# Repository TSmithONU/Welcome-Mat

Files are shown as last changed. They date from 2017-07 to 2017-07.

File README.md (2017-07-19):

# Welcome-Mat
Board files and software for WOSU Welcome Mat

The WOSU Welcome Mat consists of 7 lamps with WOSU logos. The goal of this project was to rebuild and update the previous hardware. To do this, used a Teensy 3.2, VS1053 breakout from Adafruit, and a LiDar sensor.
The LiDar sensor is calibrated to set threshold. When that threshold is crossed, it triggers playback of an audio file. The program contains a command set for use on the serial port. This allows the user to run diagnostic commands.
These include recalibration, scanning the SD card, taking a LiDar reading, and more. This repository contains the custom PCB files, as well as the teensy software.

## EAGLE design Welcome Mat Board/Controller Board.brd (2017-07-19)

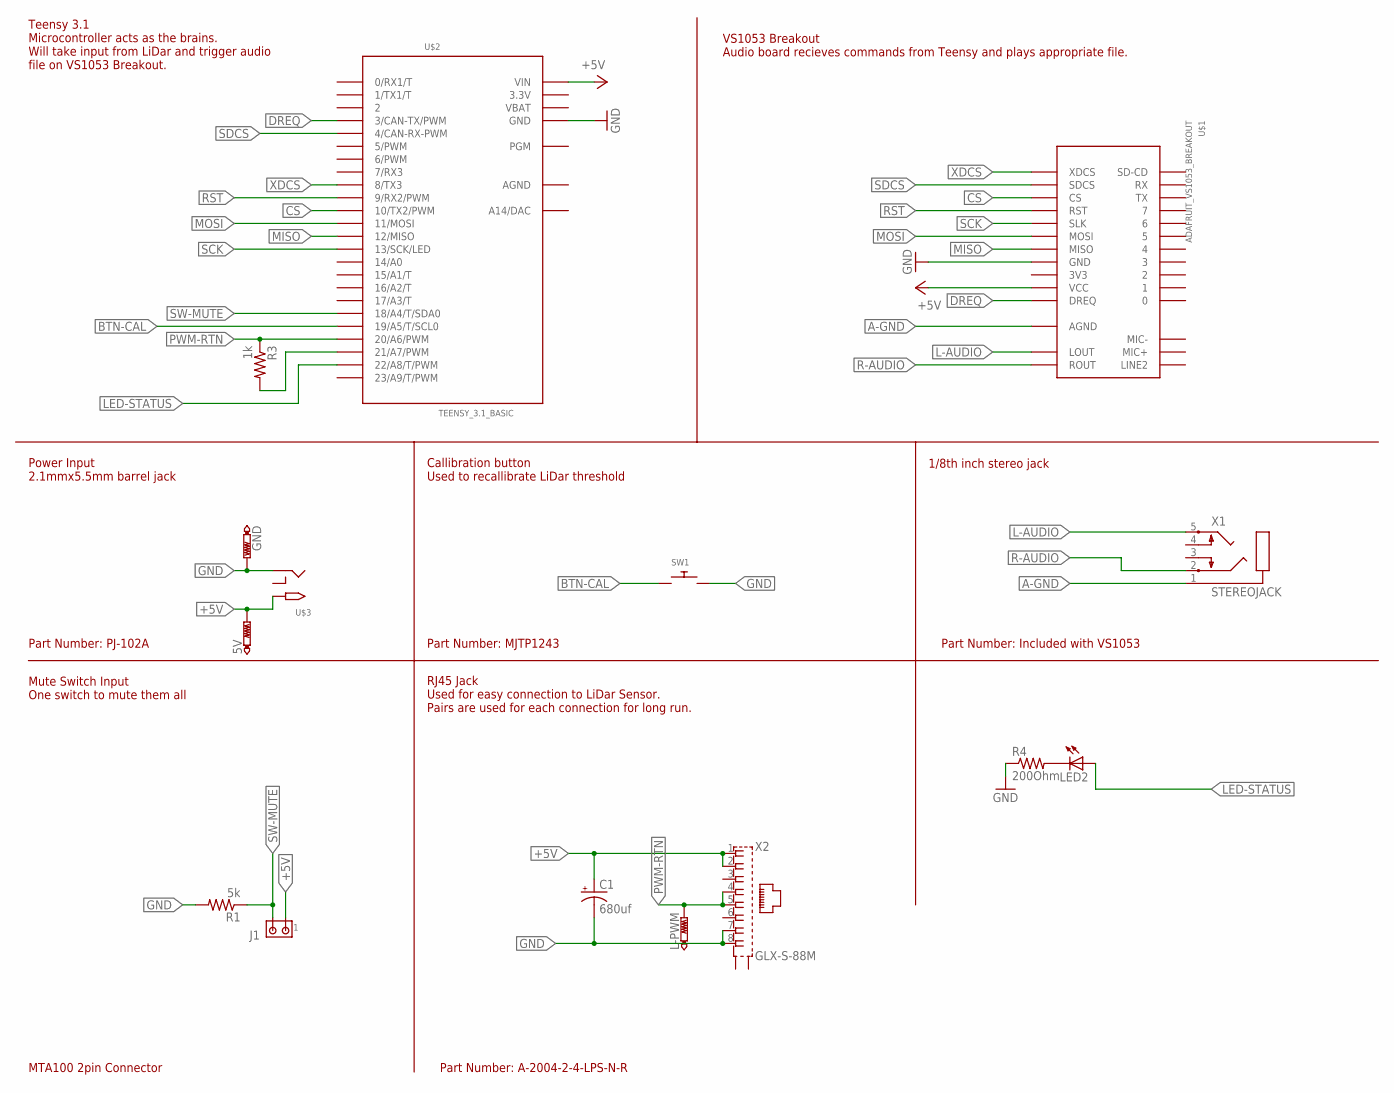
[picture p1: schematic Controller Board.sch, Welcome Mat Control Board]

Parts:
5V: PTR1PAD1-13; P1-13
C1: 680uf; E5-10,5
GND: PTR1PAD1-13; P1-13
J1: MTA02-100; 10X02MTA
L-PWM: PTR1PAD1-13; P1-13
LED2: LED3MM
R1: 5k; 0204/7
R3: 1k; 0204/5
R4: 200Ohm; 0204/7
SW1: SWITCH_PUSHBUTTONEVQ-PE; TACT_PANA-EVQ
U$1: ADAFRUIT_VS1053_BREAKOUT
U$2: TEENSY_3.1_BASIC
U$3: 2.1MMJACKTHM; PJ-102A
X1: STEREOJACK; STX3100
X2: GLX-S-88M

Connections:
3.3V: U$2.3.3V, U$2.3.3V1 (3.3V)
+5V: 5V.TP, C1.+, J1.1, U$1.P$10 (VCC), U$2.VIN, U$3.TIP, X2.1, X2.2
A-GND: U$1.P$13 (AGND), U$1.P$14 (AGND), U$1.P$20 (AGND), X1.1
AGND: U$2.AGND
BTN-CAL: SW1.P$1, U$2.19/A5 (19/A5/T/SCL0)
CS: U$1.P$3 (CS), U$2.10 (10/TX2/PWM)
DREQ: U$1.P$11 (DREQ), U$2.3 (3/CAN-TX/PWM)
GND: C1.-, GND.TP, R1.2, R4.1, SW1.P$2, U$1.P$8 (GND), U$1.P$12 (GND), U$2.GND, U$2.GND1 (GND), U$3.RING, X2.7, X2.8
L-AUDIO: U$1.P$15 (LOUT), X1.5
LED-STATUS: LED2.A, U$2.22/A8 (22/A8/T/PWM)
MISO: U$1.P$7 (MISO), U$2.12 (12/MISO)
MOSI: U$1.P$6 (MOSI), U$2.11 (11/MOSI)
unnamed: R3.2, U$2.21/A7 (21/A7/PWM)
unnamed: LED2.K (C), R4.2
PWM-RTN: L-PWM.TP, R3.1, U$2.20/A6 (20/A6/PWM), X2.4, X2.5
R-AUDIO: U$1.P$16 (ROUT), X1.2
RST: U$1.P$4 (RST), U$2.9 (9/RX2/PWM)
SCK: U$1.P$5 (SLK), U$2.13 (13/SCK/LED)
SDCS: U$1.P$2 (SDCS), U$2.4 (4/CAN-RX-PWM)
SW-MUTE: J1.2, R1.1, U$2.18/A4 (18/A4/T/SDA0)
VBAT: U$2.VBAT
XDCS: U$1.P$1 (XDCS), U$2.8 (8/TX3)

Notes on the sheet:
Teensy 3.1 Microcontroller acts as the brains. Will take input from LiDar and trigger audio file on VS1053 Breakout.
VS1053 Breakout Audio board recieves commands from Teensy and plays appropriate file.
Power Input 2.1mmx5.5mm barrel jack
Callibration button Used to recallibrate LiDar threshold
1/8th inch stereo jack
Mute Switch Input One switch to mute them all
RJ45 Jack Used for easy connection to LiDar Sensor. Pairs are used for each connection for long run.
Part Number: PJ-102A
Part Number: MJTP1243
Part Number: Included with VS1053
MTA100 2pin Connector
Part Number: A-2004-2-4-LPS-N-R

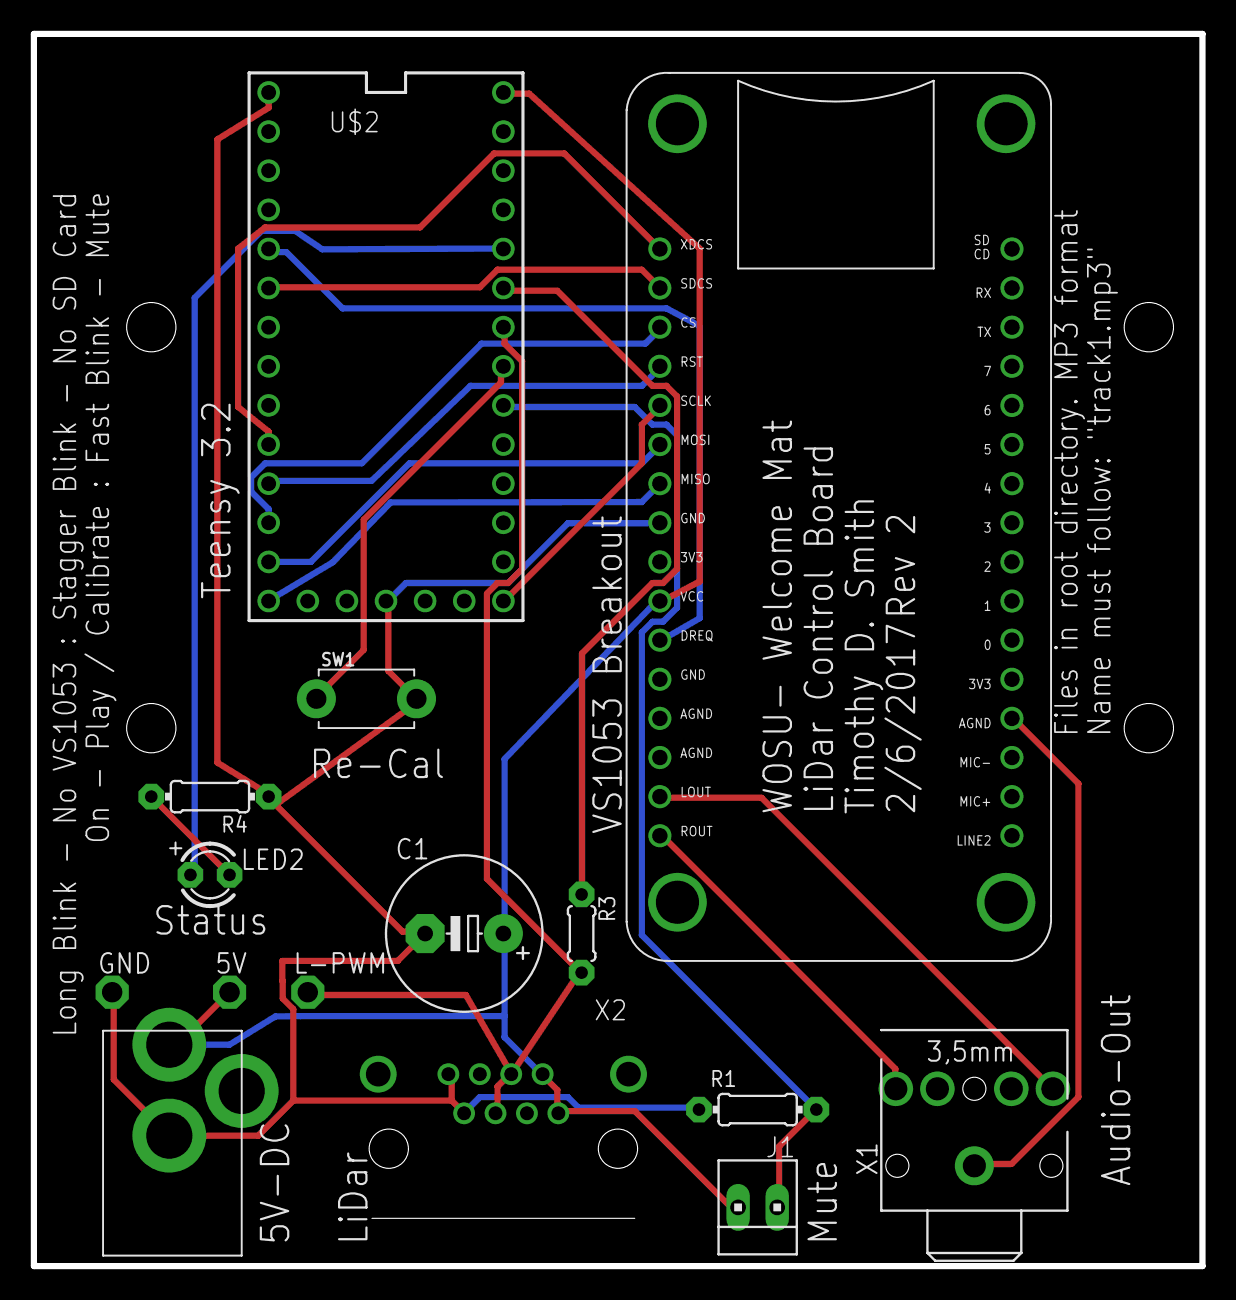
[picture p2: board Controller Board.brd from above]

Board: 2 copper layers, 75.9 x 80.0 mm, 15 parts (0 on the bottom side), 20 nets.

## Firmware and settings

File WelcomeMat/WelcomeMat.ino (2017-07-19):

#include <EEPROM.h>
#include <Bounce.h>
#include <SPI.h>
#include <Adafruit_VS1053.h>
#include <SD.h>
#include <mcmd.h>

//Function Signatures for my_commands table
void show_signon_cmd(int argc, char **argv);
void set_percentage_cmd(int argc, char *argv[]);
void list_sd_cmd(int argc, char *argv[]);
void set_sample_cmd(int argc, char *argv[]);
void report_cmd(int argc, char *argv[]);
void trigger_cmd(int argc, char **argv);
void calibrate_cmd(int argc, char **argv);
void take_reading_cmd (int argc, char *argv[]);
void help_cmd(int argc, char **argv);
void pause_cmd(int argc, char **argv);

//Lidar Lite V3 control Pins
#define lidarCtl 21
#define pwmRtn 20

//EEPROM Addresses for Thresh Percent and Sample Size
#define percentAddr 0
#define sampleAddr 100

//Contol lines for mute and cal
#define swMute 18
#define btnCal 19

//VS1053 Control Lines
#define BREAKOUT_RESET  9      // VS1053 reset pin (output)
#define BREAKOUT_CS     10     // VS1053 chip select pin (output)
#define BREAKOUT_DCS    8      // VS1053 Data/command select pin (output)
#define DREQ 3       // VS1053 Data request, ideally an Interrupt pin
#define CARDCS 4     // Card chip select pin

//Status LED line
#define stsLED 22

//VS1053 variables
//Number of tracks for loop indexing
int numtracks = 0;
//string placeholders for cancatinating
const String prefix = "track";
const String suffix = ".mp3";

//VS1053 Object
Adafruit_VS1053_FilePlayer musicPlayer = Adafruit_VS1053_FilePlayer(BREAKOUT_RESET, BREAKOUT_CS, BREAKOUT_DCS, DREQ, CARDCS);

//Bounce object for mute switch
Bounce mute = Bounce(swMute, 10);

//Variable for Lidar Reading
unsigned long pulseWidth;
//Calibrated threshold
int calThresh = 0;
int CalTemp = 0;
//Percentage for threshold calculation
float threshPercentage = .15;
//sample size for calibration readings
int sampleSize = 100;
//loop counter for audio playback
int counter = 1;
//bool varible for detecting if sensor has cycled
bool lock = false;
//pause variable for pause_cmd
bool pause = false;


//List of Serial Monitor Commands Available to user
cmd_t my_commands[] = {

  { "percent",   "        Set threshold percentage : 0-100 ",        set_percentage_cmd,    my_commands + 1   },
  { "sd",        "        List the files on the SD Card",       list_sd_cmd,   my_commands + 2   },
  { "sample",    "        Set sample size for threshold calibration : 1-1000",      set_sample_cmd,      my_commands + 3   },
  { "report",    "        Show current values",      report_cmd,         my_commands + 4   },
  { "go",        "        Simulate triggering lidar",  trigger_cmd,    my_commands + 5  },
  { "reading",   "        Take reading from sensor (opt - number of readings)", take_reading_cmd, my_commands + 6},
  { "calibrate", "Calibrate threshold",    calibrate_cmd,     my_commands + 7   },
  { "pause" ,    "        Pause trigger events", pause_cmd, my_commands + 8 },

  { "signon",    "        Show signon text",         show_signon_cmd,    my_commands + 9   },
  { "help",      "        Show available commands",  help_cmd,           my_commands + 10   },
  { "?",         "        Show available commands",  help_cmd,           NULL            },
};

//Displays available commands to user
void help_cmd(int argc, char **argv)
{
  cmd_t *p = my_commands;

  while (p) {
    Serial.print(p->cmd);
    Serial.print("\t");
    Serial.println(p->hlp);
    p = p->next;
  }
}

//Set new threshold percentage
//Updates the threshold in EEPROM
//Command input : number from 0-100
void set_percentage_cmd(int argc, char *argv[])
{
  if (argc != 2) {
    Serial.println("### Must specify percentage. 0 - 100 ###");
  }
  else if ( strtol(argv[1], NULL, 10) < 0 || strtol(argv[1], NULL, 10) > 100 ) {
    Serial.println("### Value must be between 0 and 100 ###");
  }

  else {
    threshPercentage = strtof(argv[1], NULL) / 100;
    EEPROM.put(percentAddr, threshPercentage);
    Serial.println ("Value Committed");

  }
}

void show_signon_cmd(int argc, char **argv)
{
  //show_signon();
  Serial.println("COSI WOSU Welcome Mat");
  Serial.println("Compiled: " __DATE__ ", " __TIME__ ", " __VERSION__);
  Serial.print(F("Arduino IDE version: "));
  Serial.println(ARDUINO, DEC);

}


//Displays the file tree on SD card
void list_sd_cmd(int argc, char *argv[])
{
  printDirectory(SD.open("/"), 0);
}

//Set the sample size for calabration average
//Updates value in EEPROM
//Command input: number from 0 - 1000
void set_sample_cmd(int argc, char *argv[])
{
  long int  i = 0;
  if (argc != 2) {
    Serial.println("### Must specify sample size. 1 - 1000 ###");
  }
  else if ( strtol(argv[1], NULL, 10) < 1 || strtol(argv[1], NULL, 10) > 1000)  {
    Serial.println("### Value must be between 1 and 1000 ###");
  }

  else {
    i = strtol(argv[1], NULL, 10);
    sampleSize = i;
    EEPROM.put(sampleAddr, sampleSize);
    Serial.println ("Value Committed");

  }
}

//Dispalys a list of current values. Includes percentage, sample, and more.
void report_cmd(int argc, char *argv[])
{
  Serial.print("Threshold Percentage: ");
  Serial.println(threshPercentage);
  Serial.print("Sample Size: ");
  Serial.println(sampleSize);
  Serial.print("Number of Tracks: ");
  Serial.println(numtracks);
  Serial.print("Calibrated Threshold: ");
  Serial.println(calThresh);
  Serial.print("Current Reading: ");
  Serial.println(takeReading());
}

//Triggers Playback
void trigger_cmd(int argc, char **argv)
{
  PlayTrack();
}

//recalibrates threshold
void calibrate_cmd(int argc, char **argv)
{
  CalibrateThreshold();
}

//takes a reading from lidar sensor
//Optional - number of samples
void take_reading_cmd (int argc, char *argv[])
{
  if (argc == 1) {
    Serial.print("Reading: ");
    Serial.println(takeReading());
  }

  if (argc  == 2) {
    for (int i = 0; i < strtol(argv[1], NULL, 10); i++) {
      Serial.print("Reading: ");
      Serial.println(takeReading());
    }
  }
}

//Pauses triggering of lidar. Proves useful when playback spams the serial console.
void pause_cmd(int argc, char **argv) {
  pause = ! pause;

  if (pause == true) {
    Serial.println("Paused");
  }
  else {
    Serial.println("Resumed");
  }
}

//Calibrates the threshold for kids to cross. Takes 100 readings, averages them, then applies a percentage
//to determine the threshold.
//Param: None
//Return: None
void CalibrateThreshold () {
  //Turn LED on to notify user that system is calibrating
  digitalWrite(stsLED, HIGH);
  //take set number of sample and add them together
  for (int i = 0; i < sampleSize; i++) {

    CalTemp += takeReading();
  }
  //Find average of sample
  CalTemp = (CalTemp / sampleSize);
  Serial.print("Average Reading: ");
  Serial.println(CalTemp);
  //Apply the percentage to come up with threshold that must be crossed
  calThresh = CalTemp - (CalTemp * threshPercentage);
  Serial.print("Calibrated Threshold: ");
  Serial.println(calThresh);
  //Turn LED off when finished
  digitalWrite(stsLED, LOW);
}

//Takes single reading from Lidar Sensor
//Param : None
//Return : Distance reading from Sensor
int takeReading () {
  pulseWidth = pulseIn(pwmRtn, HIGH); // Count how long the pulse is high in microseconds
  pulseWidth = pulseWidth / 10; // 10usec = 1 cm of distance
  return pulseWidth;
  //Serial.println(pulseWidth); // Print the distance
}

// Prints the SD Card Directory to the Serial Console
//Param : directory to scan, number of tabs
//Return: Number of files found in root directory
int printDirectory(File dir, int numTabs) {
  int k = 0;
  while (true) {

    File entry =  dir.openNextFile();
    if (! entry) {
      // no more files
      //Serial.println("**nomorefiles**");
      break;
    }
    for (uint8_t i = 0; i < numTabs; i++) {
      Serial.print('\t');
    }
    Serial.print(entry.name());
    if (entry.isDirectory()) {
      Serial.println("/");
      printDirectory(entry, numTabs + 1);
    } else {
      // files have sizes, directories do not
      Serial.print("\t\t");
      Serial.println(entry.size(), DEC);
      k++;
    }
    entry.close();
  }
  return k;
}

//Plays next track in loop of audio tracks
//Param : None
//Return: None
void PlayTrack() {
  //Turn status LED on to tell user track is playing
  digitalWrite(stsLED, HIGH);
  //MAke sure counter is not at end of loop
  if (counter  == numtracks + 1) {
    //reset if it is
    counter = 1;
  }
  else

    //Let I/O pin settle
    delay(10);
  //Cancatinate string to get filename
  String track = (prefix + counter + suffix);
  //Let user know which track is playing
  Serial.print("Playing: ");
  //Conversion that is required for VS1053 library
  char Track[track.length()];
  track.toCharArray(Track, track.length() + 1);
  //Print track name
  Serial.println(Track);
  //Play track through VS1053
  musicPlayer.playFullFile(Track);
  //Turn LED off when track is done
  digitalWrite(stsLED, LOW);
  //Progress track counter
  counter ++;

}

//Setup Code
void setup() {
  // put your setup code here, to run once:
  //Init Serial port for communication
  Serial.begin(9600);

  //Teensy is too fast for PC. So we wait
  delay(2000);

  //Start command system
  cmdInit(my_commands, 9600);

  //Welcome the user
  Serial.println("WOSU Welcome Mat - ' ? ' for help");

  //Update values from EEPROM
  EEPROM.get(percentAddr, threshPercentage);
  EEPROM.get(sampleAddr, sampleSize);

  //Set PinModes for input and output
  pinMode(swMute, INPUT);
  pinMode(btnCal, INPUT_PULLUP);
  pinMode(stsLED, OUTPUT);
  digitalWrite(stsLED, LOW);
  pinMode(lidarCtl, OUTPUT); // Set pin 2 as trigger pin
  digitalWrite(lidarCtl, LOW); // Set trigger LOW for continuous read
  pinMode(pwmRtn, INPUT); // Set pin 3 as monitor pin

  //if VS1053 can be found, begin communication
  if (! musicPlayer.begin()) { // initialise the music player
    Serial.println(F("Couldn't find VS1053, do you have the right pins defined?"));
    //otherwise, end program and notifiy user through status LED
    while (1) {
      digitalWrite(stsLED, HIGH);
      delay(1000);
      digitalWrite(stsLED, LOW);
      delay(1000);
    }

  }
  Serial.println(F("VS1053 found"));

  //If SD card can be found, begin communication
  if (!SD.begin(CARDCS)) {
    Serial.println(F("SD failed, or not present"));
    //otherwise, end program and notify user through status LED
    while (1) {
      digitalWrite(stsLED, HIGH);
      delay(250);
      digitalWrite(stsLED, LOW);
      delay(250);
      digitalWrite(stsLED, HIGH);
      delay(1000);
      // don't do anything more
    }

  }
  Serial.println("SD Card Found");

  //Find out how many tracks are on the sd card
  numtracks = printDirectory(SD.open("/"), 0);
  Serial.print ("Number of tracks on SD Card: ");
  Serial.println(numtracks);

  // Set volume for left, right channels. lower numbers == louder volume!
  musicPlayer.setVolume(20, 20);

  // Timer interrupts are not suggested, better to use DREQ interrupt!
  //musicPlayer.useInterrupt(VS1053_FILEPLAYER_TIMER0_INT); // timer int
  // If DREQ is on an interrupt pin (on uno, #2 or #3) we can do background
  // audio playing
  musicPlayer.useInterrupt(VS1053_FILEPLAYER_PIN_INT);  // DREQ int

  //Calibrate the trigger threshold
  CalibrateThreshold();
}

void loop() {
  // put your main code here, to run repeatedly:

  //required to use command library
  cmdPoll();
  //look for change in mute switch
  mute.update();

  //Next two if statements ensure the mute message is only displayed once
  if (mute.fallingEdge()) {
    Serial.println("Unmuted");
  }
  if (mute.risingEdge()) {
    Serial.println("Muted");
  }

  // Re-runs calibration if the button is pressed
  if (digitalRead(btnCal) == LOW) {
    CalibrateThreshold();
  }

  //Multiple conditions must be met for playback to happen
  //paused via cmd must not be true
  //system cannot be muted via switch
  //the threshold must be crossed
  //and the sensor must have gone through cycle to trigger
  //one cyle = not triggered -> triggered -> not triggered
  if (pause != true) {
    if (digitalRead(swMute) != HIGH) {
      if (takeReading() < calThresh && lock != true) {
        //PlayAudio
        lock = true;
        PlayTrack();
      }

      if (takeReading() > calThresh && lock == true) {
        lock = false;
      }
    }

    //Notify user that system is muted through LED
    else {
      digitalWrite(stsLED, HIGH);
      delay(250);
      digitalWrite(stsLED, LOW);
      delay(250);
    }
  }
}
